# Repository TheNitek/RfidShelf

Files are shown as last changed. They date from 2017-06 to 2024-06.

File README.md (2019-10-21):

# RfidShelf
Make your shelf play MP3s!

Use some cheap hardware (Esp8266/NodeMcu, RC522, VS1053 MP3 breakout board) to create an RFID controlled MP3 (and more) shelf. Impression of the first prototype:

RfidShelf Prototype (http://www.youtube.com/watch?v=39uuoB3o7k8 "RfidShelf Prototype")

RfidShelf in action (https://youtu.be/mNQsbTEaK-0 "RfidShelf in action")

This is how the first "test subject" reacted:

RfidShelf Test (http://www.youtube.com/watch?v=FcALmyrhR3w "RfidShelf Test")

## The idea
When I was a little child I loved my tapes, vinyls and later CDs. Choosing my own music or listening to Pumuckl all day. Nowadays everything is available as MP3 which makes it hard for little kids to choose their own music. Since I wanted to give my son the same possibilities I decided to start this project:

Rfid cards can the be assigned a folder containing MP3 files on a SD card, played when the card is put on the shelf. Using some creativity (and/or the Internet and a printer) those cards can be customized to represent their content, giving the kid the ability to distinguish them. A WiFi web interface gives you the ability to manage the files on the shelf and to program the cards.

## Features
* Easy to use: kids proof!
* Safe: No wiring on the outside, just a USB cable going in
* Cheap: ~ 30€ depending on the parts you choose
* Easy to manage: Web interface to configure everything needed

## Repository structure
* /Fritzing contains the sources for the wiring diagram
* /RfidShelf Arduino/platformio sources for building the firmware
* /RfidShelf/build/ current firmware image
* /ShelfBoard KiCad source files for the shelf board pcb
* /ShelfBoard/gerber current shelf board gerber files

## Tools required
* Electric drill
* Hole saw (if you don't have one, you can [get it at ikea](http://www.ikea.com/us/en/catalog/products/20302332/) together with the shelf)
* Soldering iron
* Long, stable screw driver or something similar

## Hardware
I tried a variety of hardware combinations both focusing on being cheap and easy to assemble. Based on that I can recommend a few setups, depending on your budget and your ability/willingness to solder. Most items can be bought on Aliexpress for a few bucks, the links are only meant to be an example.

### Common for all:
Some light soldering is required to attach the pin headers to the MFRC-522

* [Shelf (All Ikea Lack Shelfs and even Tables should work, but I only tried the one linked) ~6€](http://www.ikea.com/de/de/catalog/products/50282177/)
* [NodeMcu (make sure to get correct version, because the vary in size!) ~2,50€](https://www.aliexpress.com/item/V3-Wireless-module-NodeMcu-4M-bytes-Lua-WIFI-Internet-of-Things-development-board-based-ESP8266-for/32554198757.html)
* [MFRC-522 Rfid Reader ~1,50€](https://www.aliexpress.com/item/Free-shipping-MFRC-522-RC522-RFID-RF-IC-card-sensor-module-to-send-S50-Fudan-card/1623810751.html)
* [3W 8Ohm In-Ceiling Speaker ~6,50€](https://www.ebay.de/itm/Decken-Einbaulautsprecher-Mini-Halogen-Look-8cm-6cm-Einbau-weis/222389981849)
* [USB Connector ~1,50€](https://www.aliexpress.com/item/D-type-aluminum-USB-3-0-female-to-female-connector/32608847792.html)
* [Rfid Cards ~0,25€ each](http://www.ebay.de/itm/10pcs-NFC-thin-smart-card-tag-1k-S50-IC-13-56MHz-Read-Write-RFID-/172309355607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)
* Micro USB Cable + USB Power Supply (Just use one from your old smart phone)
* Jumper Wires

### Cheap (~30€)
Disclaimer: I had some noise issues with this version, probably due to all the wires flying around.
Some more light soldering is required to attach the pin headers to the amplifier.
* [Base plate for NodeMcu (also available as a kit including the NodeMcu) ~1,50](https://www.aliexpress.com/item/Nodemcu-base-plate-Lua-WIFI-NodeMcu-development-board-ESP8266-serial-port/32678372845.html)
* [VS1053 MP3 + SD Board ~6,50€](https://www.aliexpress.com/item/VS1053-VS1053B-MP3-Module-Breakout-Board-With-SD-Card-Slot-VS1053B-Ogg-Real-time-Recording-For/32809994212.html)
* [PAM8302 Amplifier ~1,00€](https://www.aliexpress.com/item/CJMCU-832-PAM8302-2-5W-single-channel-Class-D-Audio-power-amplifier-module-PAM8302A-development-board/32708571731.html)
* SD Card (NOT a micro SD but a big one!)
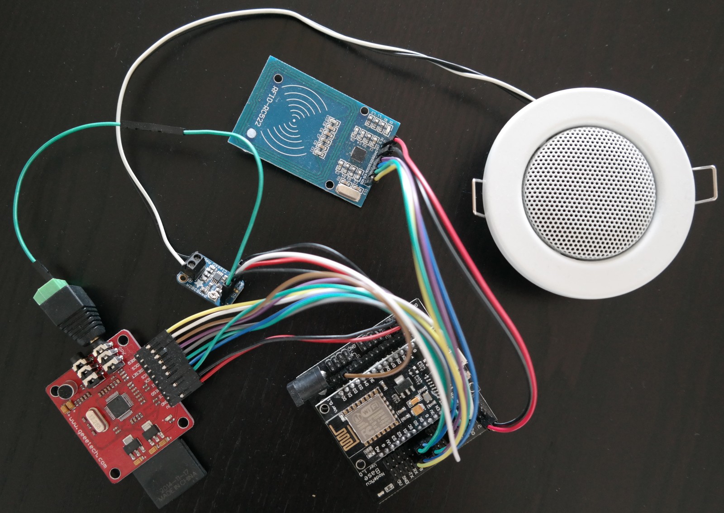
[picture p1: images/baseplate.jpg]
RfidBoardBaseplate


### ShelfBoard based (~40€)
The ShelfBoard comes in 4 pack when ordered at PCBs.io, so if you build more shelves or share with someone else, the price is quite good. Components are the same as for the "cheap" version, but instead of the base plate use the following:
* [ShelfBoard (~10,00€)](https://PCBs.io/share/z7aNg).
* [2.54mm single row female pin header - 15 pin](https://www.aliexpress.com/item/Pitch-2-54mm-2-3-4-5-6-7-8-9-10-11-12-13-14/32793723098.html)
* [2.54mm single row right angle male pin header ](https://www.aliexpress.com/item/10Pcs-40Pin-2-54mm-Single-Row-Right-Angle-Pin-Header-Strip-kit/32664627220.html)
* [2.54 single row right angle female pin header - 10 pin](http://www.ebay.de/itm/Stk-5x-BUCHSENLEISTE-HEADER-10-polig-2-54mm-Abgewinkelt-Right-Angle-A1761-/262828334819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)
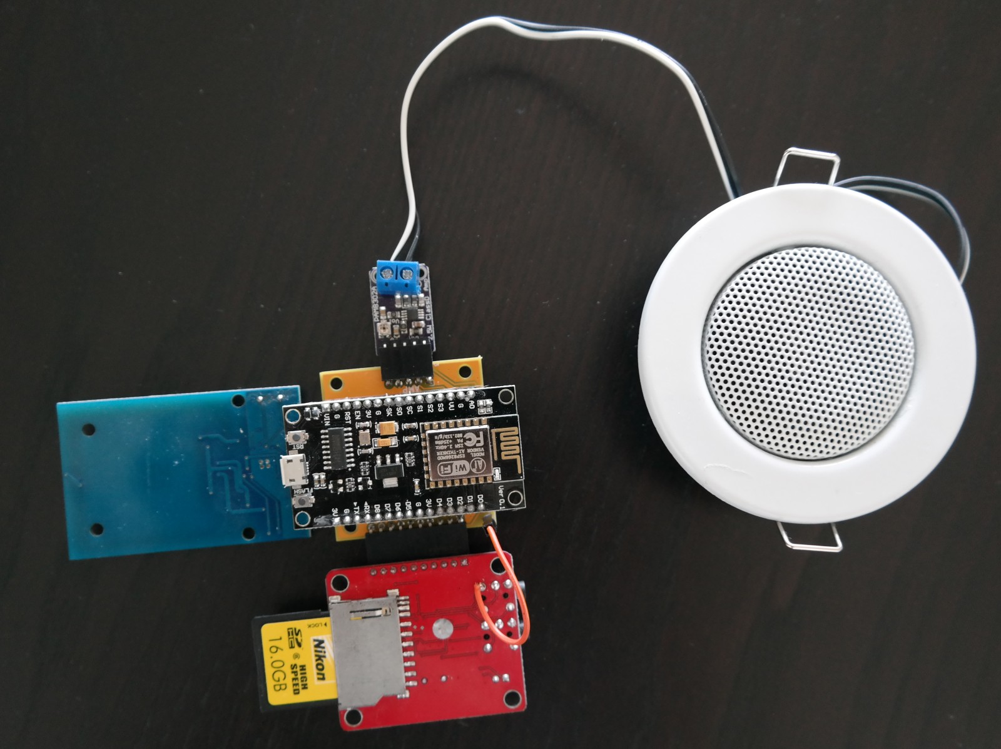
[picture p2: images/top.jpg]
RfidBoardTop

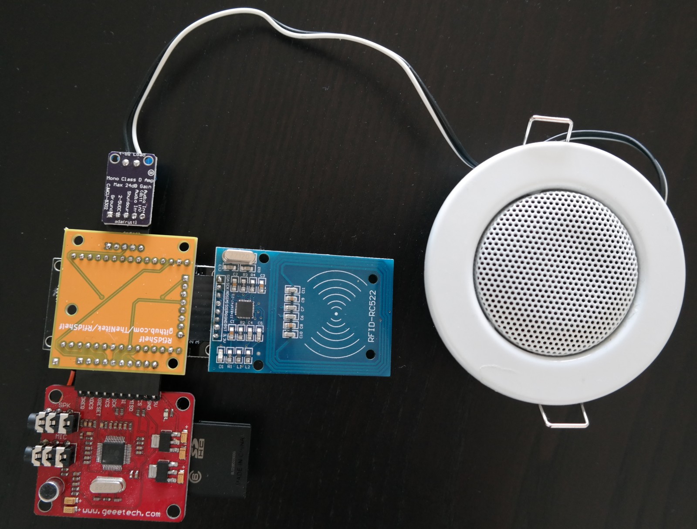
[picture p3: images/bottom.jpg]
RfidBoardBottom


### Easy (~45€)
The Adafruit board offers a good sound quality and already has an amp on board. Be sure to by the correct board, there is also a version without the amp, but a phone jack instead!
* [Base plate for NodeMcu (also available as a kit including the NodeMcu) ~1,50](https://www.aliexpress.com/item/Nodemcu-base-plate-Lua-WIFI-NodeMcu-development-board-ESP8266-serial-port/32678372845.html)
* [Adafruit Music Maker FeatherWing w/ Amp ~30,00€](https://www.adafruit.com/product/3436)
* A MicroSD Card
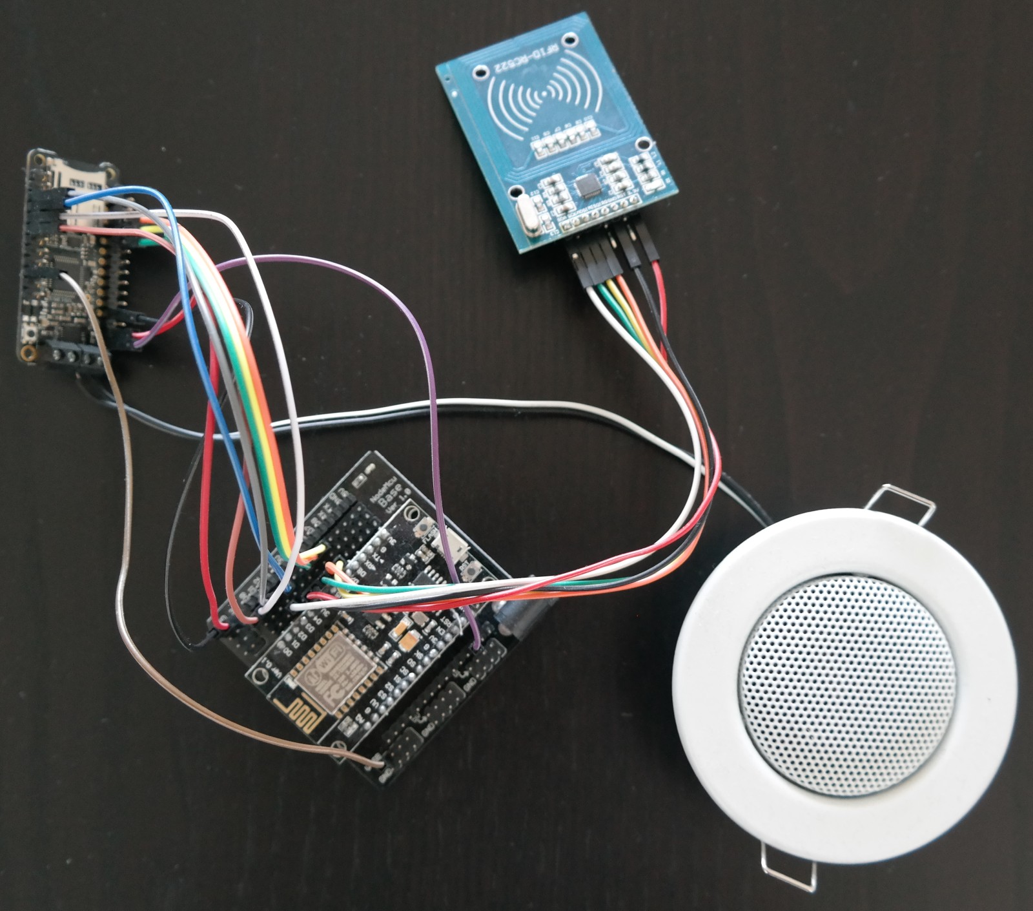
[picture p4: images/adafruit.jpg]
RfidBoardAdafruit


## Wiring
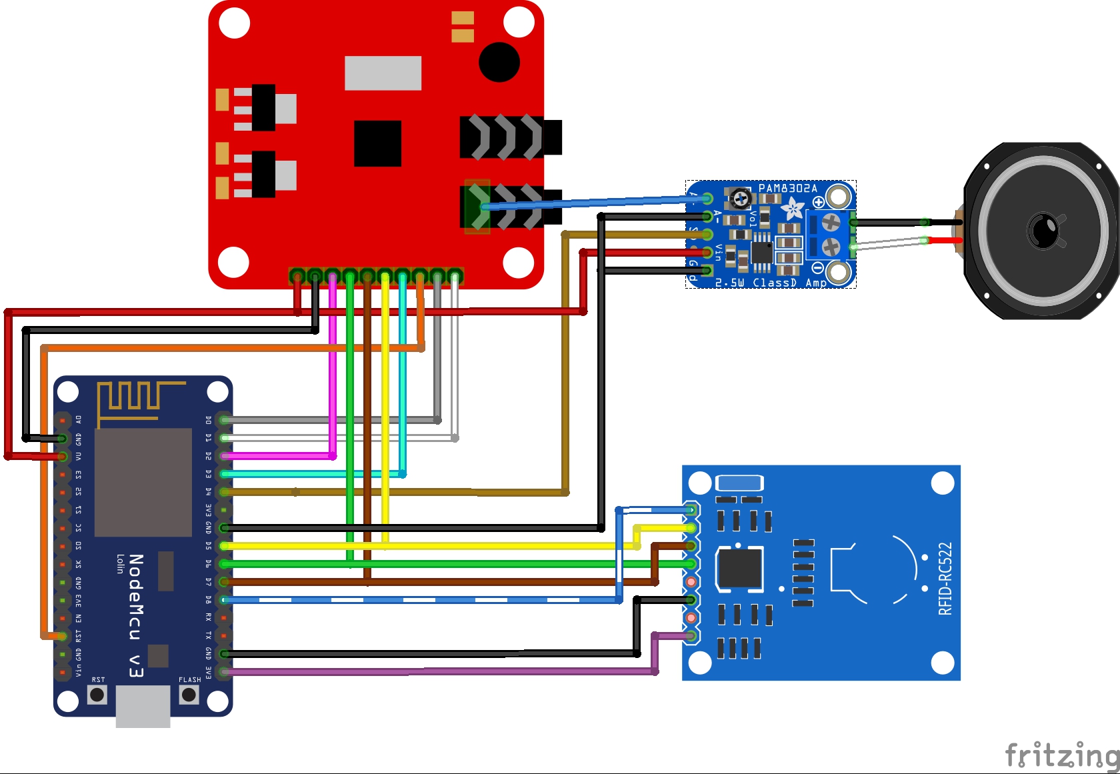
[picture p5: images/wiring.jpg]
Wiring

(See /Fritzing folder for vector/svg version if this image)
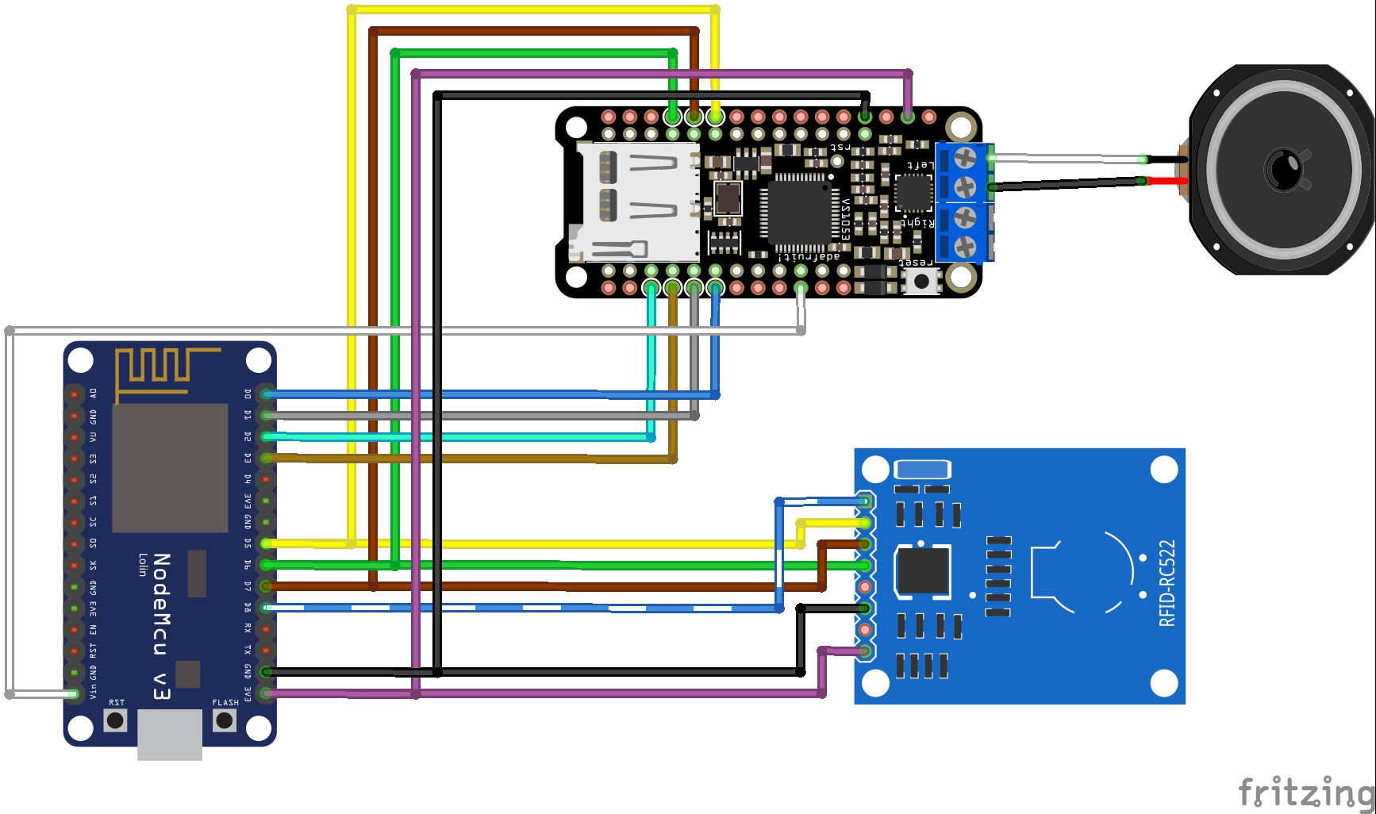
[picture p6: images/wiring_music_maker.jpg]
RfidBoardAdafruitWiring


## Build Instructions
See [hardware instructions](hardware-instructions.md)

## Firmware Flashing
See [firmware flashing](RfidShelf/installation.md)

## Random Notes
* Instead of cards you can also use those blue key fob Rfid tags, like the one included in most MFRC-522 kits. Maybe you can "implant" it into a teddy or something similar.
* Neutrik NAUSB-W seems to be a great alternative for the USB port if manage to get it for a fair price at ebay. It fits a round whole and therefore is easier to mount into the shelf.

## Similar Projects
If the RfidShelf does not fit your needs you might want to have a look here:
* [TonUINO](https://www.voss.earth/tonuino/) (german)

## Disclaimer
Everything in this project I did up to my best knowledge. Nevertheless this comes without guarantee. Do not hold me responsible in case something unexpected/undesired happens.



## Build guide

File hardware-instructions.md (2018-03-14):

# Hardware Instructions

Use the hole saw to create an opening for the speaker. For more stable mount use the 64mm drill/saw, although it makes it a little hard to install the hardware on the inside.
Make sure to put the hole on the _bottom_ of the shelf, it is very easy to get confused here. Also don't drill to deep or you'll damage the top of shelf.
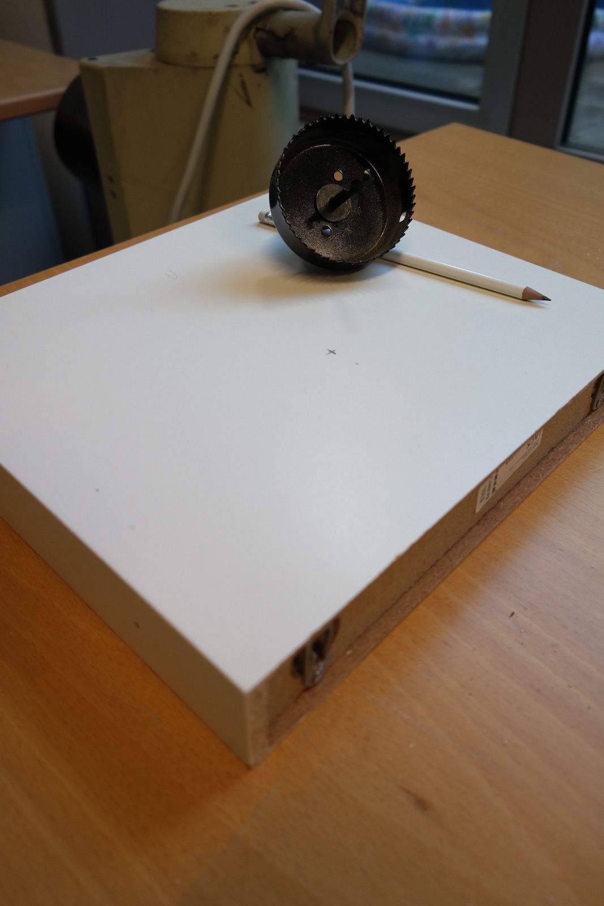
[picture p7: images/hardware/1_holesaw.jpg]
hole saw


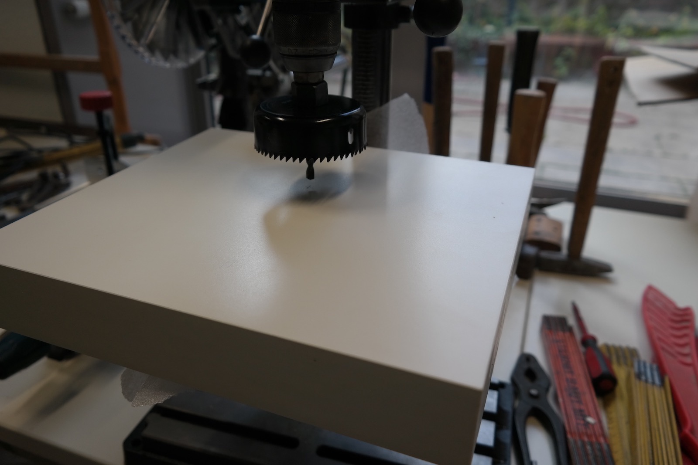
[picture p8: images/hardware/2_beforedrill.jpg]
before drilling


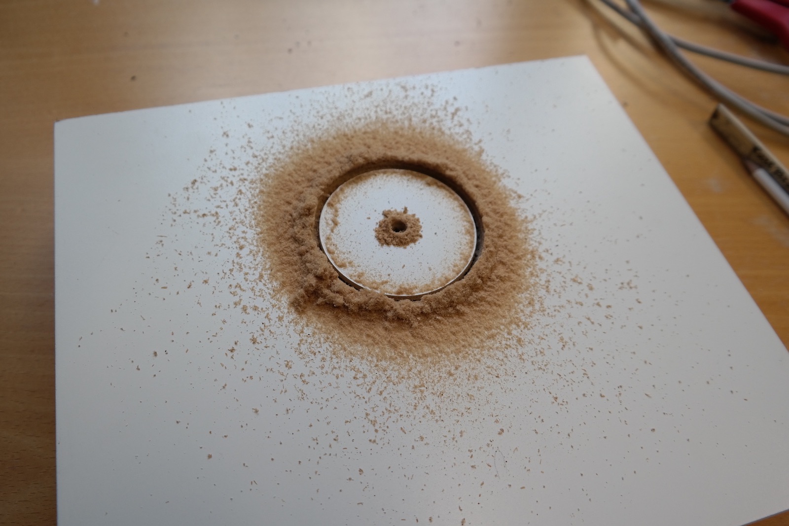
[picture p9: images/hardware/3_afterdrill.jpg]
after drilling


After sawing the hole use a screwdriver to open the shelf up.
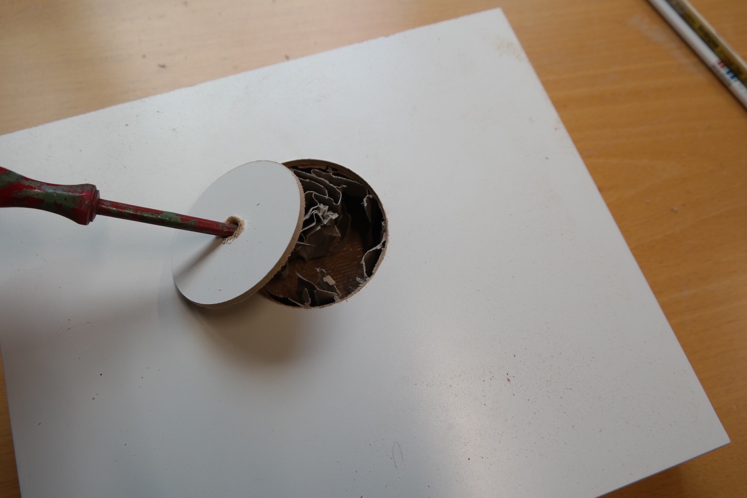
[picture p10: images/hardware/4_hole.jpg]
hole


Now you can start to remove the paper from inside.
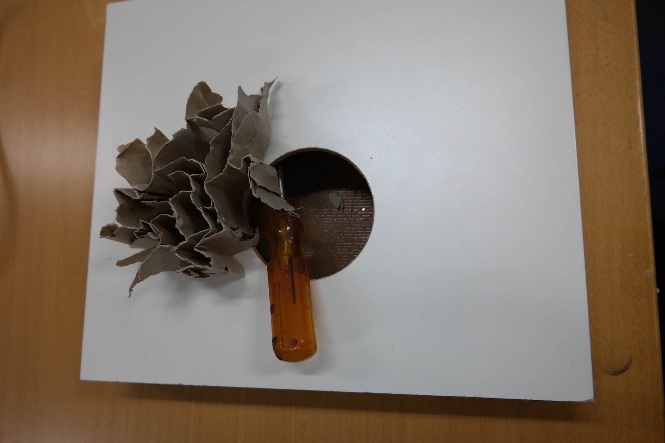
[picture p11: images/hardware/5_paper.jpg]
remove paper


I recommend removing all the paper, even though it is quite a hassle. In my experience this does not affect the stability of the shelf.
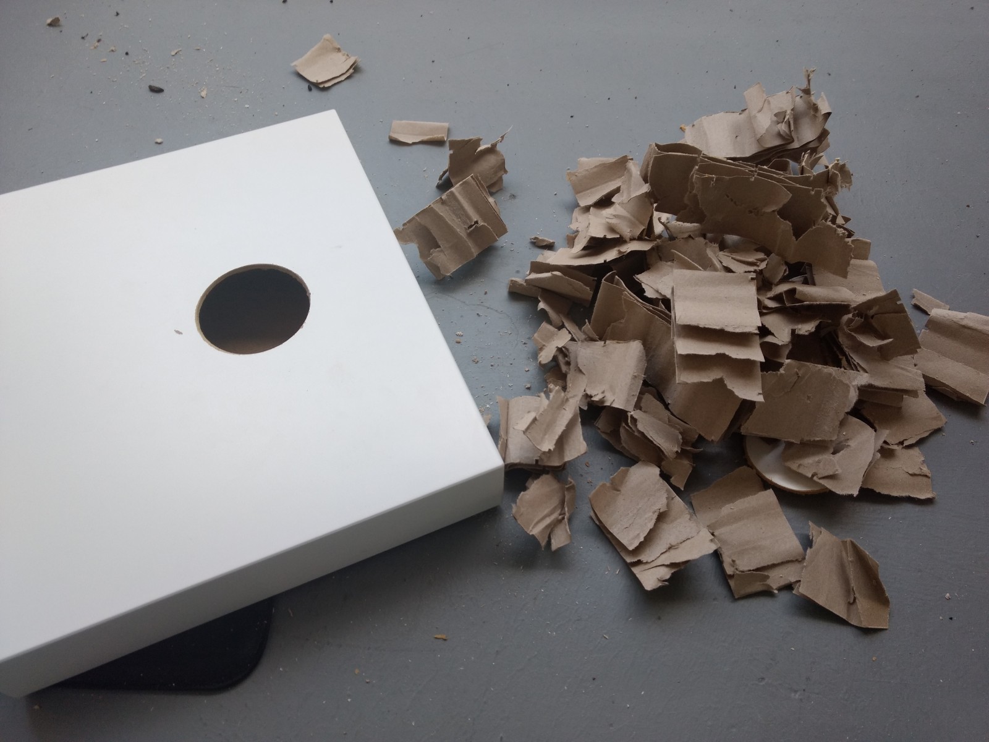
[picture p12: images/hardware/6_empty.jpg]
paper removed


Drill a hole into the side of the shelf.
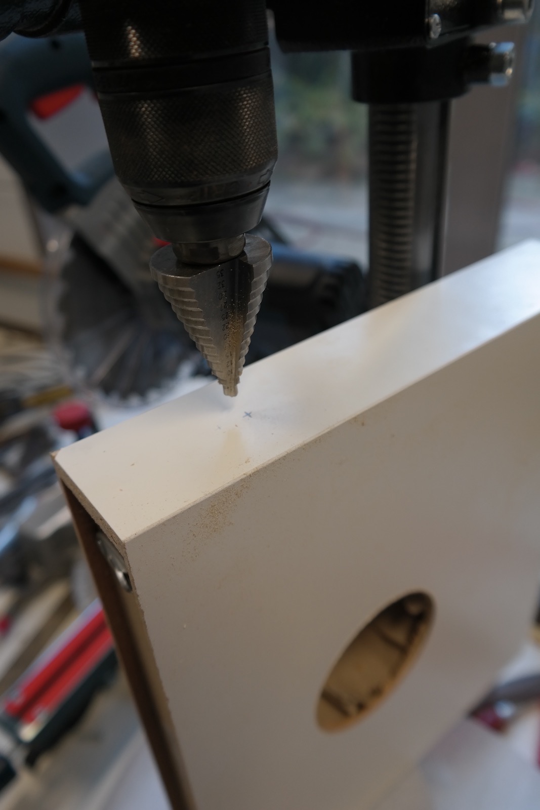
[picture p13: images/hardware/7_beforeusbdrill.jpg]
before usb connector drilling


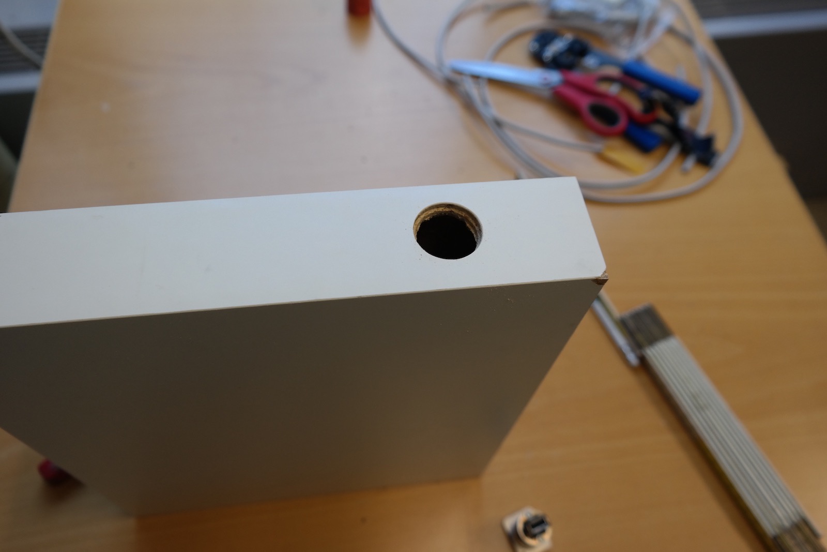
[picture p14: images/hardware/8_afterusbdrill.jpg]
after usb connector drilling


Put an USB wire through the shelf. Connect one end to the USB connector and keep the other end hanging out of the big hole.
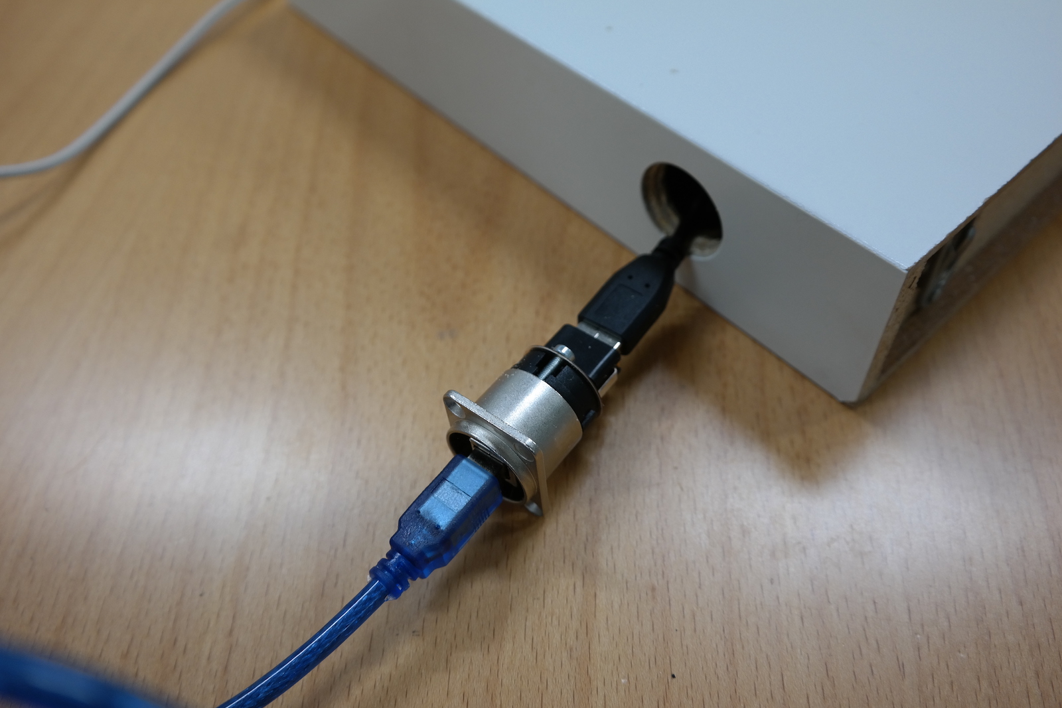
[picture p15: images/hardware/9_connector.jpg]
inserting usb connector


Place the usb connector. In most cases you can just plug it into the shelf. If it does not stick, use hot glue or some screws.
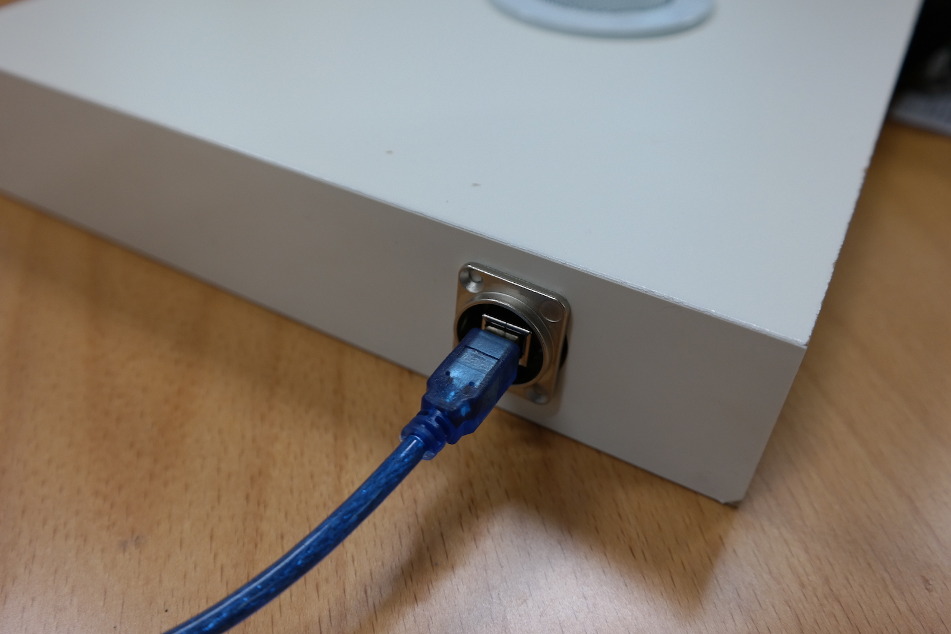
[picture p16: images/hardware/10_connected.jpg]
usb connected


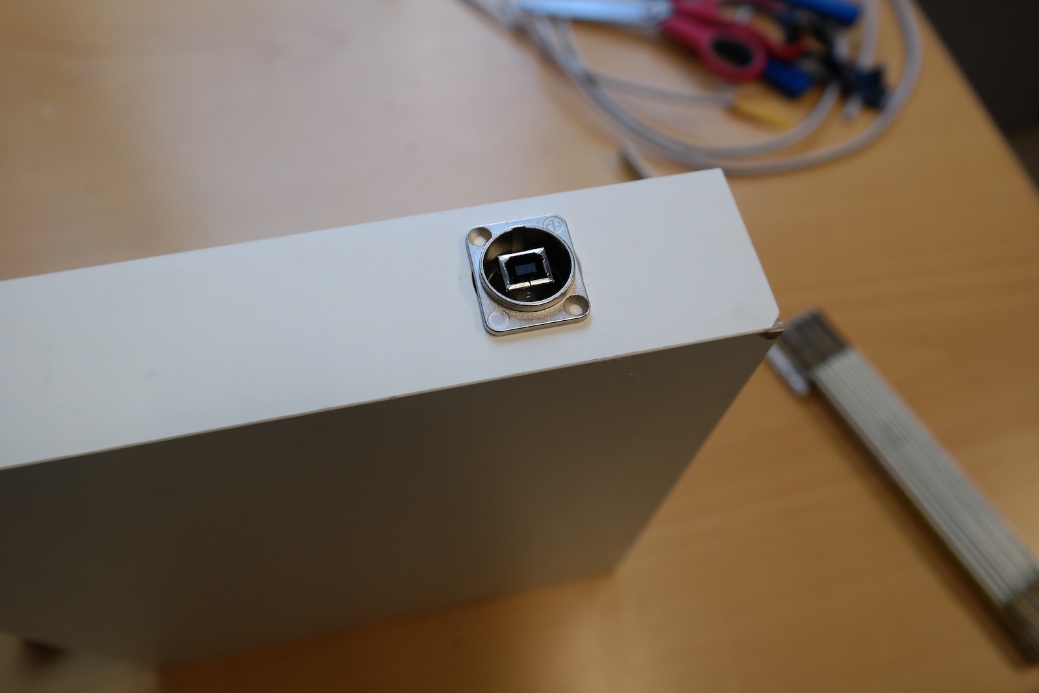
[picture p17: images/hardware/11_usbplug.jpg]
usb without cable


No it is time to put the board in. I used [plastic spacers](https://www.aliexpress.com/item/MTGATHER-100-PCS-HC-5-Nylon-Plastic-Stick-On-PCB-Spacer-Standoff-Locking-Snap-In-Posts/32794726696.html) to glue it in, but insulating tape probably also works. For easier installation, I removed the MP3 decoder board and plugged it back in, once the base board was mounted inside.
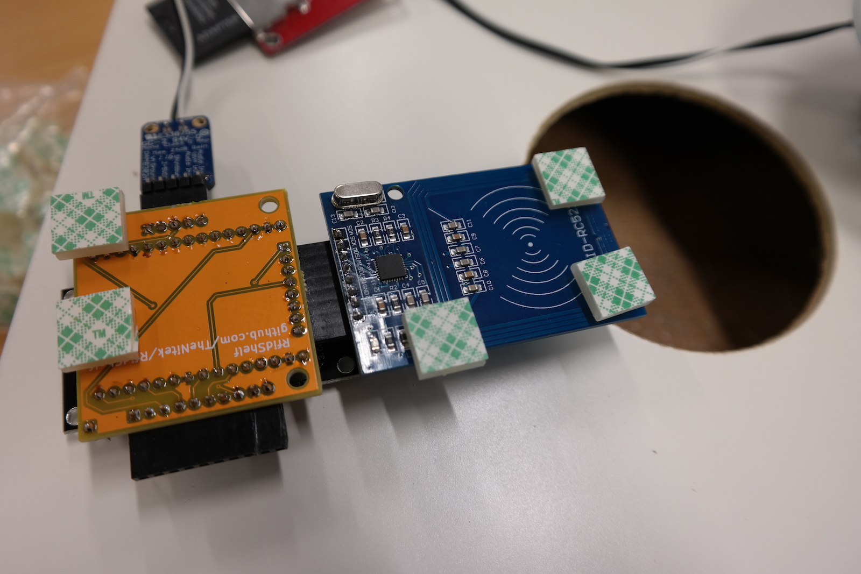
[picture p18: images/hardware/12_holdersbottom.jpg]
board bottom with holders


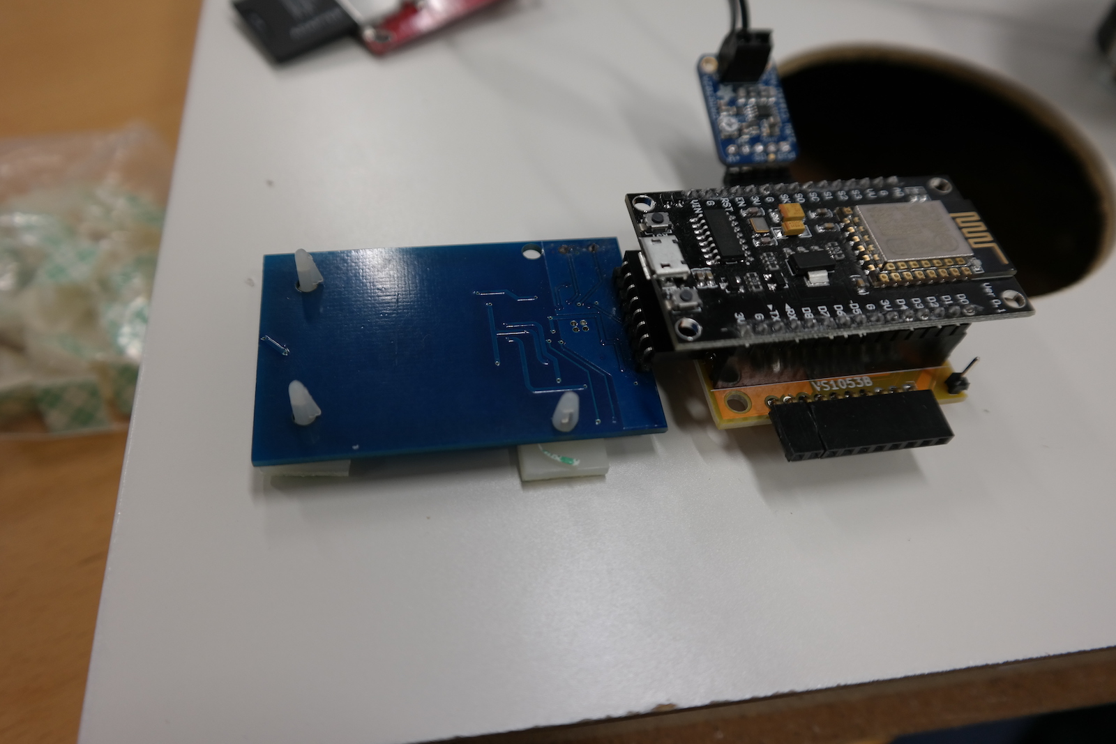
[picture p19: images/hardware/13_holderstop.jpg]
board top with holders


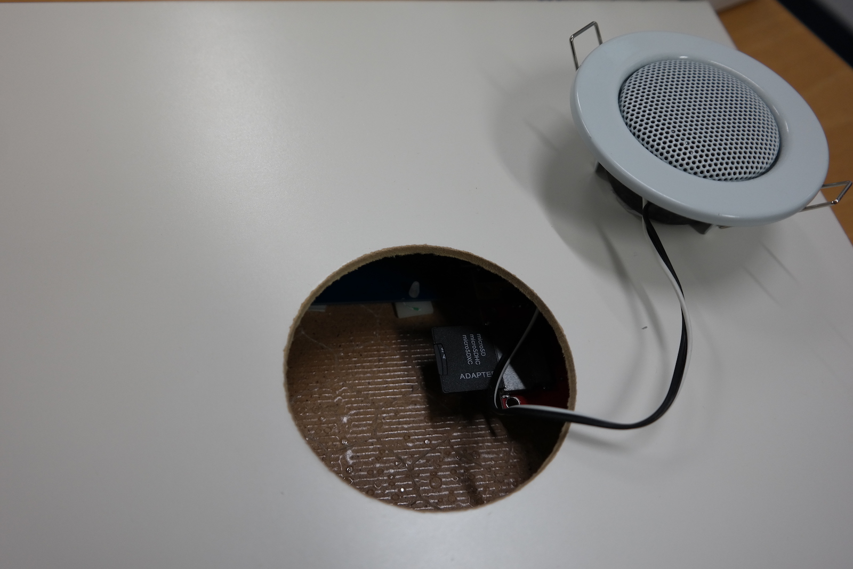
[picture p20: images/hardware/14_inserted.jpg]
board inserted


Now close the hole up by inserting the speaker. It should sit quite tight.
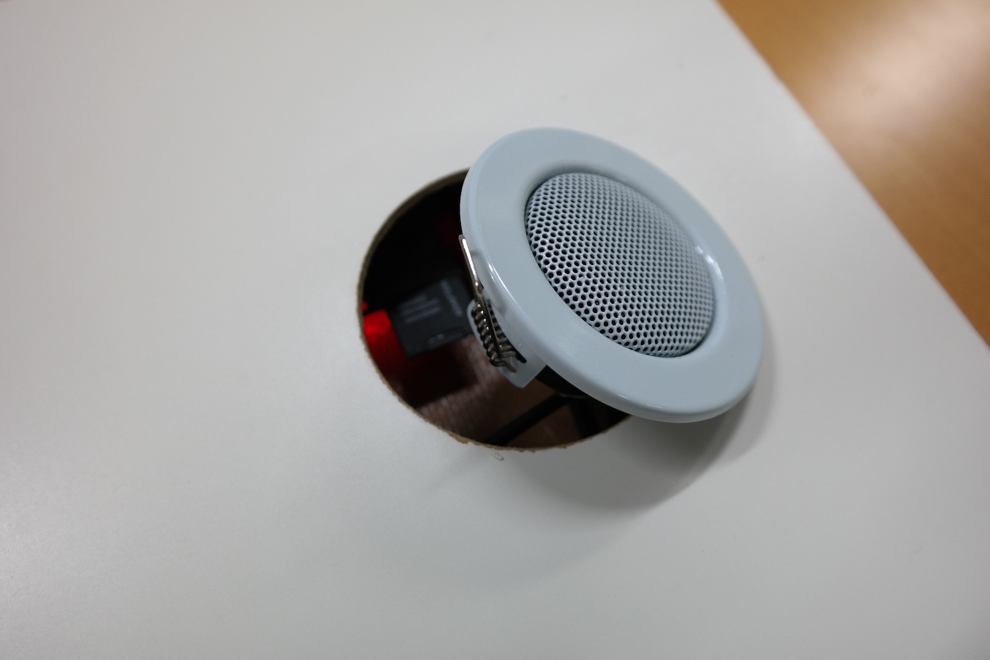
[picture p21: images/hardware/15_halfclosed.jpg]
speaker half installed


speaker installed
Now you are good to go!

Back to the [overview](README.md)

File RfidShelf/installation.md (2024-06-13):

# Firmware Installation
You either flash a pre-compiled firmware or build the software yourself using Arduino IDE or PlatformIO.

## Web Flash
Connect the ESP8266 to your computer and go to the [webflash page](https://thenitek.github.io/RfidShelf/). No further software needed!

## Using PlatformIO
1. Install [PlatformIO Core](https://platformio.org/install/cli)
1. Run "platformio run -t upload" in the RfidShelf folder

## Setup
After the firmware is flashed, the shelf will create a WiFi hotspot called "MP3-SHELF-SETUP". You can connect using the password "lacklack". In the captive portal (or on http://192.168.4.1/) you can configure your WiFi.

*Note*: Every time the shelf cannot find the configured hotspot during boot up, it will reopen this configuration WiFi.

Now you can open the shelf's web interface. For every card, you need to create a folder. Put as many MP3 files in each folder as you want. There is no need to create/upload through the web interface, just fill the SD card up before installing it into the shelf. Hit the floppy disc icon next to the folder to start the pairing mode. Place a card on the shelf afterwards. It will start playing this folder to let you know it is successfully paired. Once this happens this card will play this folder, every time it is placed on the shelf again. The current playback volume will also be stored on the card during pairing (and only then).

## Notes
* The name of the folder (and the volume) are stored on the card itself. So you can use the same card on different shelfs if the folder names are the same
* Pairing mode will overwrite cards that are already paired
* Non-MP3 files on the SD card will be ignored
* You can start/stop playback and control the volume via the web interface. The next card placed on the shelf will overwrite your commands

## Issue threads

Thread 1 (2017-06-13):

More details on the hardware workmanship

smichaelsen, 2017-06-13:
A little more detail on how you assemble and treat the hardware would be helpful for someone like me who has close to zero experience crafting physical things.

What tools do you use? (soldering iron?, saw?, wire stripper?, ...)
Can you provide a picture of the hardware fitted inside the shelf? How did you cut out the needed space?

TheNitek, 2017-06-13:
Should have added TODO notes for these sections 😀 I will add these infos step by step. Still have to take a few pictures and figure out how to draw a nice wiring picture.

Closed 2018-11-02.

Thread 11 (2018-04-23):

Stereo speakers

wallenium, 2018-04-23:
Hi There,
thanks a lot for your project. That exactly what i am searching for.

Is there any issue in using two speakers for stereo? or how is it handled? is it possible?

TheNitek, 2018-04-23:
Shouldn't be an issue. The firmware tries (only works if the VS1053 patch is available on the SD Card) to downmix the audio to mono, but it should play on both channels.

TheNitek, 2018-04-23:
Oh and of course you have to build a hardware variant that is capable of stereo playback (e.g. the adafruit board)

wallenium, 2018-04-23:
As far as I know,t he VS1053 VS1053B MP3 Module is capable of returning stereo?

Ordered the ShelfBoard, this one needs to be modified for sure. maybe sound of mono is good enough, not sure. What do you use currently? Could cancel most components and use adafruit, works as well.

another question: posible to use an external sd card slot to be able to add it to the shelf itsself?

TheNitek, 2018-04-23:
Yes, the MP3 module is able to play stereo, but I try to enable the mono downmix so no audio is lost when using one speaker only.

The ShelfBoard is designed for a mono amplifier, so while it might be possible to connect a stereo one (I did this in the earlier stages of development) it is not ideal. The adafruit board has the stereo amp integrated, so while not being the cheapest solution, it is most probably the most easy one.
If you want to keep it cheap you can try something like this in combination (note: there might be cheaper version of this around, just looked for the first one I could find): https://www.aliexpress.com/item/1pcs-3-5MM-3Pole-Gold-plated-Plug-Free-Welding-Dual-Channel-Audio-Headphone-Plug-Stereo-Adapter/32833822485.html and https://www.aliexpress.com/item/Mini-PAM8403-3W-two-2-Channel-Way-Double-Track-Power-Audio-Amplifier-Module-Volume-Adjustment-Stereo/32857928954.html

Any SPI SD card reader should work (on the board it is actually also a sd slot separated from the mp3 decoder part, the just happen to be on the same board by "coincidence"), but you probably don't need it since you can manage the files via the web interface.

wallenium, 2018-04-23:
adafruit: most easy or best sound?

I guess the adafruit should have a better quality than the VS1053 VS1053B.. at least the specs are better ;) I ordered one. Adafruit is stable..

Web interface sounds nice.

One last question: easy solution for a button-based (+ and -) volume control?

TheNitek, 2018-04-24:
Well to be honest: This is not a hifi solution, so I would not get my hope to high regarding sound quality. This works perfectly for kids room but of course it cannot compete with a professionel hifi solution.

Volume control is currently not possible and something that I planned for the webinterface. There are no more GPIOs available for hardware controls (if I remember correctly there is still an analog port available which might work, bit I am not sure right now)

wallenium, 2018-04-24:
yes, i know. will test the mono version first. Quality should be good enough. Should be for my kids room, will work. The old device we currently use is bad quality of sound, should be better.

Thanks a lot for your effort and support. I'll test if analog port is working once i receive the last parts...  if you have a further idea, would be great to share.

wallenium, 2018-12-17:
Just one question: Have you worked with IO extenders such as https://de.aliexpress.com/item/MCP23017-Serial-Interface-Module-IIC-I2C-SPI-MCP23S17-Bidirectional-16-Bit-I-O-Expander-Pins-10Mhz

Maybe this would work to extend the GPIO and add possibilities for hardware buttons (volume, next/previous track). Analog potentiometer would be an option for volume, but not the best solution...

BeAr1987, 2018-12-18:
I made a fork with a poti for volume control a few versions ago, you can find my code here: https://github.com/BeAr1987/RfidShelf

TheNitek, 2018-12-18:
I didn't go for IO expanders, because I wanted to keep this project as cheap and easy to use as possible. Nevertheless it should be possible to add one (I guess you could even add the poti directly to the speaker wires without any software integration at all - but I'm not 100% sure).

Looking at the options today, I'd probably start the project with an ESP32 now which should offer enough GPIOs of the shelf (and a few other nice bonus features).

Closed 2018-08-17.

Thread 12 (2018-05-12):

How to set up and run the firmware

smichaelsen, 2018-05-12:
Please bear with me, this really is my first micro electronics project.

I used the [nodemcu-flasher](https://github.com/nodemcu/nodemcu-flasher) to flash the firmware from this repo onto my NodeMCU (well there was no error and a blue LED was flashing, so I suppose it worked). But I don't know how to proceed. How do I start the firmware? Do I need additional software like ESPlorer? A few examples I found were related to the Arduino which is not applicable here I guess.

I can read docs or tutorials but I need a pointer into the right direction.

TheNitek, 2018-05-12:
Well there is some documentation missing on this topic ;-) Just created #13 as a reminder.

Use some kind of serial terminal software (like putty or arduino IDE) to connect to the devices serial port and watch the output for error messages. If there are none, you should be able to see a new wifi network named "RfidShelf" (Password "lacklack"). If you join the Wifi you will get a setup page to connect to your own wifi. Once this is done you can access the admin page via your wifi. There you can upload music or start the card pairing.

Closed 2018-08-17.

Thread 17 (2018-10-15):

Support for 125 kHz Reader EM4100

hankman13, 2018-10-15:
Hi,
do you think that it's possible to add support for the 125 kHz Reader (EM4100/RDM6300/RDM630) [AliExpress](https://de.aliexpress.com/item/Free-shipping-UART-125Khz-EM4100-RFID-Card-Key-ID-Reader-Module-RDM6300-RDM630-For-Arduino/32279622758.html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,searchweb201602_5_10320_10065_10068_318_10547_319_10546_317_10548_10696_450_10084_10083_10618_452_535_534_10304_533_10307_10820_532_204_10843_10059_10884_10887_100031_320_10103_448_449,searchweb201603_60,ppcSwitch_0&algo_expid=7ae266ba-59ad-488b-935f-e58f10581791-0&algo_pvid=7ae266ba-59ad-488b-935f-e58f10581791&transAbTest=ae803_4)
I own this device and i would like to use these cards, because I'm already using a RFID Jukebox from this project: [RPi-Jukebox-RFID](https://github.com/MiczFlor/RPi-Jukebox-RFID)
I think your solution will be more friendly for power consumption.
Thanks!

One more thing, could you please add a picture of you Webinterface? I'm still collecting and waiting for my chinabag for building the RFID Shelf.

TheNitek, 2018-12-13:
Sorry for the late feedback. I guess 125kHz support should be possible, but nothing this project supports right now. Feel free to create a pull request.

I'll add a picture soon, right now it is just the main area I am working on and I didn't won't to have to update the screenshot everytime I change something (or have an outdated screenshot).

Closed 2018-12-13.

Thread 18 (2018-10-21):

Add "night mode"

TheNitek, 2018-10-21:
Add a special mode which reduces the volume for all cards to a night-compatible level

TheNitek, 2019-07-28:
It's no possible to active "night mode" via the web interface. It will reduce the volume until there is are 5 minutes without playback (so you won't loose the night mode when switching cards)

Closed 2019-07-28.

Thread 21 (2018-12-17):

Increase Upload Speed

TheNitek, 2018-12-17:
Currently the upload speed is around 100kb/s do bigger files take ages. A increase in upload speed would be nice. Ideas are welcome ;-)

TheNitek, 2018-12-31:
Tried my best, but the ESP8266 doesn't seem to offer a better speed for HTTP Uploads ...

TheNitek, 2019-11-10:
FTP upload might be an option. Seems to increase the upload speed compared to http

leachiM2k, 2020-02-20:
Did you try the upload with ESPAsyncWebServer?

TheNitek, 2020-02-20:
I've been thinking about this for a while now, but the AsyncWebServer is a dangerous step regarding race conditions and would need some major rework on the web control code

leachiM2k, 2020-02-21:
I tried it here: https://github.com/leachiM2k/RfidShelf/tree/feature/async-webserver
and so far it compiles. But I have to test it on the device itself.
It was not as much work as I thought.

TheNitek, 2020-02-29:
Making it compile isn't what worries me, but making it run stable. I expect a major refactoring of the web handlers to be necessary to prevent race conditions.

TheNitek, 2020-03-01:
Using ESPAsyncWebServer seems to even reduce the throughput to around 70kb/s - That's unexpected ands disappointing

mkuger, 2020-11-18:
Assuming sound quality is not that of an issue: try and reduce bitrate in browser before uploading?

Closed 2020-12-23.

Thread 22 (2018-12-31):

Switch back to official Adafruit VS1053 lib

TheNitek, 2018-12-31:
Switch back to official Adafruit VS1053 lib once https://github.com/adafruit/Adafruit_VS1053_Library/pull/49 is merged

TheNitek, 2019-01-29:
Postponed, since SdFat support is not working 😞

Closed 2020-02-01.

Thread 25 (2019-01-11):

Hardware Button support

Tedious01, 2019-01-11:
Hi,
really nice project, I thing I'd like to build it. Just one question - AFAIK there are software buttons in web server. Would it be possible to implement hardware button support (Play/Pause, Vol up, Vol down)? Or is this already implemented and I didn't find it. Would be great if the childs would be able to pause etc. just by a button...
Best regards from Hessen,

Sascha

TheNitek, 2019-01-11:
There is (well hidden) short discussion about hardware buttons here: #11
In short: Not supported right now and there is only a limited number of PINs left to use. Also @BeAr1987 has a fork which supports volume control.

Tedious01, 2019-01-11:
Thanks for your feedback, I'll have a look it.

TheNitek, 2019-10-09:
After a little bit of thinking:
Volume is not a problem using the analog in
Maybe GPIO01 and 03 (RX/TX for the serial connection) can be used for additional buttons - if wired correctly, even the USB flashing should still continue to work (although serial debugging won't be possible anymore)

TheNitek, 2019-10-09:
You can now set BUTTONS_ENABLE in ShelfConfig.h to use TX for pause/resume, RX for skip track and A0 for volume control.

Closed 2019-10-09.

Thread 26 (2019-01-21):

VS1053 initializes sporadically

SiJoNi, 2019-01-21:
This is my first project with microcontrollers so far and i am facing a little issue.
It seems that my setup only starts in about half of the cases. When it is not working it fails at initializing the music player. (!_musicPlayer.begin()) I have to switch power off completey and then repower it to try again. If I get past this point everything is working as expected. Did you had similiar issues?

Thanks a lot for sharing this cool project. I hope my son will have as much fun as I have with it.

TheNitek, 2019-01-21:
What setup are you running? The red VS1053 board? Did you wire it using jumper wires? How long are the wires? Did you check each of them? My guess would be the wiring. Of all the stupid things that happend during the development, I never had any issues like that with the VS1053.

SiJoNi, 2019-01-21:
I am running the setup with the Adafruit Music Maker FeatherWing. Yes it is wired with jumper cables (10 cm). I will exchange all of them to see if I can fix it this way. Thanks for the quick help.

SiJoNi, 2019-01-21:
After resoldering the VS1053 and replacing every jumper wire it finally works. Thanks a lot and keep up the good work.

TheNitek, 2019-01-21:
Nice, thanks for the feedback! I'd be happy to see some pictures once you finished your build ;-)

Closed 2019-01-21.

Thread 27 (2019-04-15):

Can't connect & flash once everything is assembled

leachiM2k, 2019-04-15:
Hello,
thank you a lot for this project. It's pretty cool. I'm already using a phoniebox, but want to have a more stable and speedier solution. But...
I've soldered every part to one system with wires (no jumper cables) and have now the issue that I can't connect to NodeMCU by USB anymore. Is it possible that wiring there is an issue with a connection if some of the ports are used by other hardware? I've read something about a special role of GPIO 0 (D3)...
Do you know something about it? Or did you have similar issues?

TheNitek, 2019-04-15:
Glad you like my project :-)
I had trouble from time to time to get the ESP to flash, but not in general. I the serial terminal still working? If not my guess would be incorrect wiring, because that should always work.
If it does, you can try to manually enter flash mode using the buttons on the ESP.

Did you change the PIN compared to my design? Is the shelf firmware already on? Because I noticed that a delay at the beginning of setup() helps to improve the reliability of flashing, so it's part of the firmware.

leachiM2k, 2019-04-17:
Ok, I took my time and checked everything again and again. I tried it with a different ESP8266 and had the same issue. 🤔
In the end I had two power-only USB cables that provide no data connection.

Now everything is working, but somehow laggy... Every time I open the webpage the player stops working for a second.

I have two questions:
- Is it true, that you can not upload mp3 files through web interface?
- Why did you wire A- of the amplifier to GND on board instead of the audio jack on VS1053 like you did with A+?

TheNitek, 2019-04-18:
The web interface interferes with the mp3 playback. I don't think there is an easy way to avoid that, but I don't consider it a problem, since I use the web for admin propuses only. You can use it to upload MP3s. Works quite well, but the WiFi performance makes it somewhat annoying when uploading bigger files.

Since I didn't get differential output to work, the AMP only needs GND and one of the audio signals. GND from the VS1053 wouldn't be any different.

Closed 2019-04-17.

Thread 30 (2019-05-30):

Port to ESP32

TheNitek, 2019-05-30:
ESP32 would allow the use of Bluetooth and probably remove the need for the VS1053 while adding more pins, performance and other nice features. The price hase went down by now, so it looks like a nice step forward.

Think about:
* Can the ESP8266 still be supported?
* Which ESP32? Maybe the AI Thinker Audio Board?

Any thoughts?

warhog, 2019-05-30:
I also thought about using the ESP32 (funny note, it was yesterday evening while showing the radio to a friend :) ). It shouldn't be an issue to have support for ESP8266, I did this in a project already and with some preprocessor ifdefs this can be done. The libs are almost the same.

Pinwise its a good idea, I've built a portable variant (description to follow) using LiIons and have not enough pins left for features like battery management and state feedback, ...

I dunno the complexity of playing music files on the ESP directly but quick googling showed up ESP8266Audio (works for ESP32 also) lib that can do the job. Might be an idea to reduce hardware complexity a bit and give additional features. Maybe some research is needed on quality (both of my VS1053  are quite noisy).

While the AI Thinker Audio Board is quite nice it lacks IOs (e.g. ADC1) for my use case. With careful planning we might be (almost) independent of the used board (but with increased complexity).

It think all in all it is also a question of the projects direction and the target audience. New boards introduce complexity both on HW and SW level. At least from my side I'm short on time always (second child, parental time is sadly over now).
As a conclusion I really like the idea but I think an analysis with pros and cons is needed.

Or we just give it a try, maybe it is so great that we drop ESP8266 support :D

TheNitek, 2019-05-30:
Well I don't think using ifdefs will work too well, because there will be too many differences (audio output, SD access ...). Branching seems to more reasonable i guess.

The AI Thinker Board has a BAT-Port included and I like how it already brings an SD-slot and the amp. Unfortunately it doesn't look like it provides SPI for the Rfid reader, so it's probably not any option anyway.
Main objective of this project is and should be to be simple, so the ESP32 solution shouldn't become any more complex than the current one - Simplification would be very welcome (that's why the AI Thinker board is so appealing).
I'd love to support web radio (using an ESP32 with PSRAM) und Bluetooth Audio. Also using a I2S amp seems good for sound quality.

If you have noise on your VS1053 it's probably the SPI wiring. Only way for me to get rid of this was use my PCB. That solved any noise issues.
BTW I'd love to see what you made out of this project, so if you have more to share I'd be more than interested ;-)

torwag, 2019-06-17:
Being new to this, I was wondering, the switch to an ESP32 board would also solve #25, as the limitation of GPIOs seems to be the challenge here. Furthermore, more GPIOs would enable battery charging, LEDs and other additional features in the future. As for replacing the VS1053 with ESP software, I guess it would only make sense, if the software solutions shows great benefits over the dedicated chip solution. Usually, that is quite a bit of work and bug-prone as well, thus, a dedicated chip might be complex on the soldering side, but easier on the software stack side.
I am looking into a (possible portable) device which I can easily configure via the webinterface, including adding new cards and files, but which can be controlled by the kids with the usual three button control (play/pause, vol+/skip and vol-/rev).

warhog, 2019-06-22:
I've just gave it a quick try using an ESP32 dev board and Adafruit UDA1334A I2S breakout using this code https://github.com/schreibfaul1/ESP32-audioI2S. I have not tested SD yet but streaming is working.
Using my headphones the audio quality of the tested webstreams was stunning.
Regarding the pins it improves the situation (about 10 pins are free when using SD card).
Hardware complexity is almost equal: ESP32 board, I2S board, SD board and amplifier board(s).
I'm a bit short on time due to kids and heavy workload in the company but I'll try to continue playing with it for eval purposes.

TheNitek, 2019-06-22:
I did nearly the same using https://www.aliexpress.com/item/Max98357-I2S-3W-Class-D-Amplifier-Breakout-Interface-Dac-Decoder-Module-Filterless-Audio-Board-For-Raspberry/33004419753.html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 (so no need a additional amplifier board) and I was also very pleased.
I was thinking about the ESPs SD controller, but it seams that SPI-SD-readers are cheaper than SD slots with additional electronics.
Additional pins would also allow for the RFID reader to use interrupts.

All in all I am quite tempted but I fear that I also might not have enough free time to get this done right now.

TheNitek, 2020-01-03:
Out of scope for now

Closed 2020-01-03.

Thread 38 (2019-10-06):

Compress HTML during build

TheNitek, 2019-10-06:
Currently the HTML code increases the firmware size even if it's only spaces for formating. Having a build step which minimizes and compress the HTML/Javascript would be nice to keep to footprint as small as possible.

Idea is to have the HTML in a template file which is compress/minimized by a python script within the platformio build process and then inserted into the C++ code. This should happen in a way that ArduinoIDE can still build the firmware, even though a HTML Update is not possible.

Closed 2019-10-12.

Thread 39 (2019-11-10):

Play folder doesn‘t update playback info

TheNitek, 2019-11-10:
When hitting the play button on a folder the playback info on top of the page is not updates.

TheNitek, 2019-12-14:
Fixed by https://github.com/TheNitek/RfidShelf/commit/d524398dd646a786caed2985fadb165f18bdc71b

Closed 2019-12-14.

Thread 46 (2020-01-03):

Repeat/Halt/Shuffle Flag on cards have to be nullable

TheNitek, 2020-01-03:
Repeat/Halt/Shuffle Flag on cards are currently not nullable so there is no "use whatever is set for the shelf" option. This should be reworked.

Closed 2020-01-06.

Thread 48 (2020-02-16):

Add Alexa Support

TheNitek, 2020-02-16:
Make "play" and "pause" (and maybe night mode/volume) work through Alexa

leachiM2k, 2020-02-20:
Great idea. I’ve already implemented this feature in a Raspberry version of TonUINO. I used MQTT for communication as it works very well with firewalls and different WiFi installations.
Do you have ideas about the implementation?

The main problem is the song name recognition. Therefore I used only numbers as folder names.

TheNitek, 2020-02-20:
I'd go with a simple on/off using https://github.com/igorantolic/esp32-alexa-wemo-emulator Anything more seems to be beyond the scope if this project.

TheNitek, 2020-04-18:
Implemented

Closed 2020-04-18.

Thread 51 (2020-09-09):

PlatformIO won't compile Code

Clautens, 2020-09-09:
Hi!
really nice projxct. I build a version of RfidShelf for my son some years ago. Now I need a second one for my daughter!
I downloaded your project and opened the "RfidShelf" folder in PlatformIO.
I'm using an ESP8266 Lolin-Board with an Adafruit FeatherWing. If I hit the Build-Button the following error occurs, followed by some other errors which I think they are all related to the first one:

```
.pio\libdeps\nodemcuv2\SD/utility/Sd2PinMap.h:371:2: error: #error Architecture or board not supported.
 #error Architecture or board not supported.
  ^
```
The Dependency Graph shows the following:

```
|-- <Adafruit VS1053 Library> 1.2.0
|   |-- <SD> 0.0.0-alpha+sha.041f788250
|   |   |-- <SPI> 1.0
|   |-- <SPI> 1.0
|-- <BoolArray> 0.2.0
|-- <DNSServer> 1.1.1
|   |-- <ESP8266WiFi> 1.0
|-- <EasyButton> 2.0.0
|-- <ESP8266WebServer> 1.0
|   |-- <ESP8266WiFi> 1.0
|-- <ESP8266WiFi> 1.0
|-- <ESP8266HTTPClient> 1.2
|   |-- <ESP8266WiFi> 1.0
|-- <ESP8266httpUpdate> 1.3
|   |-- <ESP8266WiFi> 1.0
|   |-- <ESP8266HTTPClient> 1.2
|   |   |-- <ESP8266WiFi> 1.0
|-- <ESP8266SdFat> 1.1.0
|   |-- <SPI> 1.0
|-- <MFRC522> 1.4.6
|   |-- <SPI> 1.0
|-- <SPI> 1.0
|-- <WifiManager> 0.15.0
|   |-- <DNSServer> 1.1.1
|   |   |-- <ESP8266WiFi> 1.0
|   |-- <ESP8266WebServer> 1.0
|   |   |-- <ESP8266WiFi> 1.0
|   |-- <ESP8266WiFi> 1.0
|-- <Espalexa> 0.0.0-alpha+sha.09981160b5
|   |-- <ESP8266WiFi> 1.0
|   |-- <ESP8266WebServer> 1.0
|   |   |-- <ESP8266WiFi> 1.0
|-- <ArduinoOTA> 1.0
|   |-- <ESP8266mDNS> 1.2
|   |   |-- <ESP8266WiFi> 1.0
|   |-- <ESP8266WiFi> 1.0
|-- <ESP8266mDNS> 1.2
|   |-- <ESP8266WiFi> 1.0
|-- <SD> 0.0.0-alpha+sha.041f788250
|   |-- <SPI> 1.0
```

Could you please give me a hint what I'm doing wrong?
Thank you!

TheNitek, 2020-09-09:
Best guess: Platformio just released there new 5.0 core which changed the dependency resultion. I guess that might lead to the wrong SD library being included. I‘ll have closer look tomorrow.

TheNitek, 2020-09-10:
I fixed the SD dependency, so it should compile now. Thanks for reporting this!

Clautens, 2020-09-17:
Works like a charm! thank you very much!

Closed 2020-09-10.

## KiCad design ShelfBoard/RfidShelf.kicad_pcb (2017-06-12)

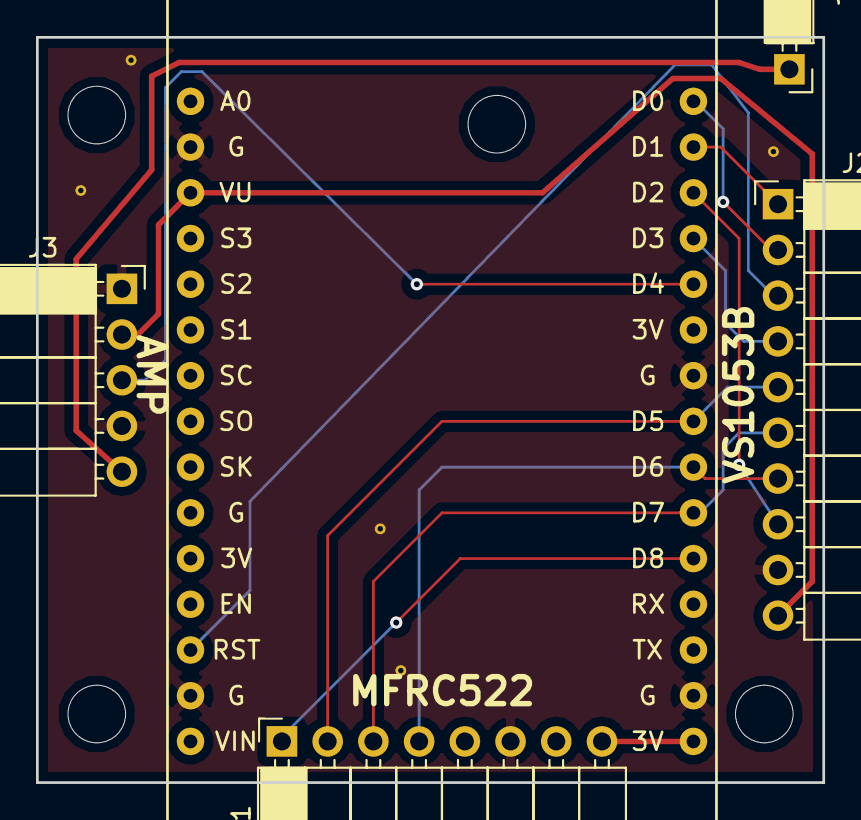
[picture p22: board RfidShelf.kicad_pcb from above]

Board: 2 copper layers, 43.7 x 41.4 mm, 5 parts (0 on the bottom side), 14 nets.

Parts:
J1: RC522 Header; Socket_Strip_Angled_1x08_Pitch2.54mm
J2: GEEETECH_MP3; Socket_Strip_Angled_1x10_Pitch2.54mm
J3: Amplifier; Socket_Strip_Angled_1x05_Pitch2.54mm
J4: Audio In; Socket_Strip_Angled_1x01_Pitch2.54mm
U1: NodeMCU_1.0_(ESP-12E); NodeMCU1.0(12-E)

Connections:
+3V3: J1.8, U1.16
+5V: J2.10, J3.2, U1.3
/AMP_SLP: J3.3, U1.26
/AUD+: J3.5, J4.1
/DREQ: J2.1, U1.29
/MISO: J1.4, J2.7, U1.22
/MOSI: J1.3, J2.6, U1.21
/RF_CS: J1.1, U1.20
/RST: J2.3, U1.13
/SCLK: J1.2, J2.5, U1.23
/SD_CS: J2.8, U1.28
/XCS: J2.4, U1.27
/XDCS: J2.2, U1.30
GND: J1.6, J2.9, J3.1, J3.4, U1.2, U1.14, U1.17, U1.24

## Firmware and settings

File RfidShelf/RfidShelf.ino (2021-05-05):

#include <Arduino.h>
#include "ShelfPins.h"
#include "ShelfConfig.h"
#include <ESP8266WiFi.h>
#include <WiFiManager.h>
#include <SdFat.h>
#include <SD.h>
#include <ESP8266mDNS.h>
#include <time.h>
#include <coredecls.h>        // settimeofday_cb()
#include "ShelfPlayback.h"
#include "ShelfRfid.h"
#include "ShelfWeb.h"
#include "ShelfPodcast.h"

#ifdef ARDUINO_OTA_ENABLE
#include <ArduinoOTA.h>
#endif

#ifdef BUTTONS_ENABLE
#include "ShelfButtons.h"
#endif

sdfat::SdFat sdCard;

ShelfConfig config;
ShelfPlayback playback(config, sdCard);
ShelfRfid rfid(config, playback);
ShelfWeb web(config, playback, rfid, sdCard);
ShelfPodcast podcast(config, playback, web, sdCard);
#ifdef BUTTONS_ENABLE
ShelfButtons buttons(config, playback);
#endif

void timeCallback() {
  Sprint("Time updated: ");
  time_t now = time(nullptr);
  Sprintln(ctime(&now));
}

void setup() {
#ifdef DEBUG_ENABLE
  Serial.begin(115200);
#endif
  Sprintln();
  Sprintln(F("Starting ..."));

  // Init SPI SS pins
  pinMode(RC522_CS, OUTPUT);
  digitalWrite(RC522_CS, HIGH);
  pinMode(SD_CS, OUTPUT);
  digitalWrite(SD_CS, HIGH);
  pinMode(BREAKOUT_CS, OUTPUT);
  digitalWrite(BREAKOUT_CS, HIGH);
  pinMode(BREAKOUT_DCS, OUTPUT);
  digitalWrite(BREAKOUT_DCS, HIGH);

  randomSeed(analogRead(A0));

  // Load config
  config.init();

  rfid.begin();
    
  //Initialize the SdCard.
  if (!sdCard.begin(SD_CS) || !sdCard.chdir("/")) {
    Sprintln(F("Could not initialize SD card width SdFat"));
    sdCard.initErrorHalt();
  }
  Sprintln(F("SDFat ready"));
  if(!SD.begin(SD_CS, SPI_FULL_SPEED)){
    Sprintln(F("Could not initialize SD card with SD"));
  }
  Sprintln(F("SD ready"));


  playback.begin();

  if(strcmp(config.ntpServer, "") != 0) {
    settimeofday_cb(timeCallback);
    configTime(config.timezone, config.ntpServer);
  }


  Sprint("Hostname: "); Sprintln(config.hostname);
  WiFi.hostname(config.hostname);

  WiFiManager wifiManager;
  wifiManager.setConfigPortalTimeout(3 * 60);
  if (!wifiManager.autoConnect("MP3-SHELF-SETUP", "lacklack")) {
    Sprintln(F("Setup timed out, starting AP"));
    WiFi.mode(WIFI_AP);
    if (WiFi.softAP("MP3-SHELF", "lacklack")) {
      Sprintln(F("Soft-AP is set up"));
    } else {
      Sprintln(F("Soft-AP setup failed"));
    }
  }

  if(WiFi.isConnected()) {
    Sprint(F("Connected! http://")); Sprintln(WiFi.localIP());
  }

  if (!MDNS.begin(config.hostname)) {
    Sprintln("Error setting up MDNS responder!");
  }

#ifdef ARDUINO_OTA_ENABLE
  // TODO move into EEPROM config
  ArduinoOTA.setPassword((const char *)"shelfshelf");
  ArduinoOTA.begin();
#endif

  web.begin();

#ifdef BUTTONS_ENABLE
  buttons.begin();
#endif

  playback.startFilePlayback("", "ready.mp3");

  Sprintln(F("Init done"));
}

void loop() {
  MDNS.update();

  web.work();

  // Skip the rest while file is uploading to improve performance (playback won't work anyway)
  if(web.isFileUploading()) {
    return;
  }

#ifdef BUTTONS_ENABLE
  buttons.work();
#endif

#ifdef ARDUINO_OTA_ENABLE
  ArduinoOTA.handle();
#endif

  playback.work();

  rfid.handleRfid();

  podcast.work();
}

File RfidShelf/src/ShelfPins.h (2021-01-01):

#pragma once

#define RC522_CS        D8
#define SD_CS           D2

#define BREAKOUT_RESET  -1    // VS1053 reset pin (output)
#define BREAKOUT_CS     D3    // VS1053 chip select pin (output)
#define BREAKOUT_DCS    D0    // VS1053 Data/command select pin (output)
#define DREQ            D1    // VS1053 Data request (input)

#define AMP_POWER       D4

#define PAUSE_BTN       D10   // GPIO1 = TX
#define SKIP_BTN        D9    // GPIO3 = RX
#define VOLUME          A0

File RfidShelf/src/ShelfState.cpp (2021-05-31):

#include "ShelfState.h"

void ShelfState::storeState(ShelfState_t state) {
  ShelfStateEnvelope_t env;
  env.state = state;
  // Update CRC32 of data
  env.crc32 = _calculateCRC32((uint8_t*) &(env.state), sizeof(env.state));
  // Write struct to RTC memory
  if(!ESP.rtcUserMemoryWrite(0, (uint32_t*) &env, sizeof(env))) {
    Sprintln(F("Failed to write state to RTC memory"));
  }
}

bool ShelfState::loadState(ShelfState_t &state) {
  ShelfStateEnvelope_t env;
  if (ESP.rtcUserMemoryRead(0, (uint32_t *) &env, sizeof(env))) {
    uint32_t crcOfData = _calculateCRC32((uint8_t*) &(env.state), sizeof(env.state));
  #ifdef DEBUG_ENABLE
    Serial.print(F("CRC32 of data: "));
    Serial.println(crcOfData, HEX);
    Serial.print(F("CRC32 read from RTC: "));
    Serial.println(env.crc32, HEX);
  #endif
    if (crcOfData != env.crc32) {
      Sprintln(F("CRC32 mismatch. State invalid!"));
      return false;
    } else {
      Sprintln(F("CRC32 match"));
      memcpy(&state, &(env.state), sizeof(env.state));
      return true;
    }
  }
  return false;
}

uint32_t ShelfState::_calculateCRC32(const uint8_t *data, size_t length) {
  uint32_t crc = 0xffffffff;
  while (length--) {
    uint8_t c = *data++;
    for (uint32_t i = 0x80; i > 0; i >>= 1) {
      bool bit = crc & 0x80000000;
      if (c & i) {
        bit = !bit;
      }
      crc <<= 1;
      if (bit) {
        crc ^= 0x04c11db7;
      }
    }
  }
  return crc;
}

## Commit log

2017-02-16 Added initial version of arduino code
2017-06-04 * Added platform.io build* Added travis-ci file* Optimized wiring* Play files in alphabetical order
2017-06-12 Restructured project to include RfidShelfBoard and extended README.md
    [RfidShelf-B.Cu.gbl, RfidShelf-B.Mask.gbs, RfidShelf-B.SilkS.gbo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]
2017-06-14 Added wiring diagram
    [wiring.fzz]
2017-06-16 Minor changes
    * Reformated wiring diagramm
    * Added list of required tools
    [RfidShelf.sch, wiring.fzz]
2018-01-06 Add currently playing + play button to web interface. Fixed filter to play only mp3 files
    [RfidShelf.ino]
2018-01-15 Improved tag handling (#8)
    * #7 Stop playback when card is removed. Todo: Playback started via web
    * #7 revert something stupid
    * #7 make web triggered playback work again
    [RfidShelf.ino]
2018-03-10 added wiring schematics for Adafruit Music Maker Featherwing integration (#9)
    * added wiring schematic for adafruit, inkl. fritzing file
    [wiring_music_maker.fzz]
2018-08-17 Added volume control and stop buttons to web interface
    Fixed webinterface with esp8266 2.4.2
    [RfidShelf.ino]
2018-08-17 Fix underflow in volume control
    [RfidShelf.ino]
2018-08-18 Fix default volume handling for legacy cards
    [RfidShelf.ino]
2018-09-05 Http stream (#15)
    * Allow http playback via web interface
    * Fixed file deletion
    [RfidShelf.ino]
2018-12-17 Improved WebUI * Added progress bar for file upload * Added client side sorting for sd content * Display file size (to make it easier to spot failed uploads)
    [RfidShelf.ino]
2019-01-10 Restructure files (#24)
    * First version that compiles without errors \o/
    * Try to fix travis.ci build
    * Make web interface work again
    [RfidShelf.ino, ShelfPins.h, ShelfPlayback.cpp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]
2019-01-12 added basic bass&treble control fixed deprecation warnings
    [ShelfPlayback.cpp]
2019-01-12 only show play file button on mp3 files
2019-01-12 Improved playFile. Added skip button. Bumped version
    [ShelfPlayback.cpp, ShelfRfid.cpp]
2019-04-26 playback: fix value clamping in volumeUp() (#28)
    [ShelfPlayback.cpp]
2019-05-27 Some improvements and fixes (#29)
    * moved configuration to separate central file, added pushover notification service, bumped version
    * fix missing timer restart
    * updates regarding new esp8266 sdk (2.5.2)
    * added auto download for vs1053 patches
    * lot of changes
    * move ifdef to correct position
    [RfidShelf.ino, ShelfPlayback.cpp]
2019-06-30 Don't use volume bar as upload progress indicator. Switch +/- buttons
2019-07-28 Implemented #18 (night mode) and removed HTTP playback since it doesn't work anyway
    [ShelfPlayback.cpp, ShelfRfid.cpp]
2019-09-21 Rework web interface (1st step), initial integration of NTP in preparation of #33
    [RfidShelf.ino]
2019-09-25 Lots of refactoring and hopefully fixing #37
    [RfidShelf.ino, ShelfPlayback.cpp, ShelfRfid.cpp]
2019-09-25 Fix the bugs the refactoring introduced
    [ShelfRfid.cpp]
2019-10-21 Switch to github build status badge
2019-12-14 Fix #40, fix uninitialized array nextFile, pin esp8266 framework version due to incompatible new version
    [ShelfPlayback.cpp, ShelfRfid.cpp]
2019-12-19 Make MDNS work and add option for ArduinoOTA
2020-01-03 Added card-specific configuration options & dialog (#44)
    * Accept OTA urls from outside
    * added first draft of a card configuration dialog
    * config to own struct, write and read new params
    * implemented stopOnRemove and repeat
    * play some status mp3 files
    * fixed volume setting
    * updated build files
    * renamed randomMode to shuffleMode, connected to card configuration
    * Clarified the use of WiFi.softAP return value
    * comparison of RFID_CONFIG_VERSION is more explicit
    [RfidShelf.ino, ShelfPlayback.cpp, ShelfRfid.cpp]
2020-01-03 Remove broken startup sounds
    [RfidShelf.ino, ShelfPlayback.cpp]
2020-01-25 Fix pairing and make config flags a bit more intuitive
    [ShelfRfid.cpp]
2020-01-27 Add debugging output (fix happend in the VS1053b lib)
    [ShelfPlayback.cpp, ShelfRfid.cpp]
2020-01-28 Rework RFID config handling. Reset pairing form after pairing
    [ShelfPlayback.cpp, ShelfRfid.cpp]
2020-01-29 Stop playback when pairing happens. Don't show firmware update in sub folders. Don't play card if reading config block fails
    [ShelfPlayback.cpp, ShelfRfid.cpp]
2020-01-31 Migrate to newest espressif8266 version and switch to back to roriginal Adafruit VS1053 lib (fixing #22)
    [RfidShelf.ino, ShelfPlayback.cpp]
2020-12-23 Tweak upload performance (Resolves #21 until someone got a better idea)
    [RfidShelf.ino]
2021-05-05 #50 improved podcast loading, add auto cleanup of old episodes and try to reduce heap usage (download still crashes from time to time)
    [RfidShelf.ino, ShelfPodcast.cpp]
2021-05-08 Rework char[] handling and project structure
    [RfidShelf.ino, ShelfPins.h]
2022-01-22 Rework config and fix VS1053 patch download
    [RfidShelf.ino, ShelfPodcast.cpp]
2023-01-27 Fix build with latest 3.1.1 core - Finally adds UTF8 support for file names
    [RfidShelf.ino, ShelfPlayback.cpp, ShelfPodcast.cpp]
